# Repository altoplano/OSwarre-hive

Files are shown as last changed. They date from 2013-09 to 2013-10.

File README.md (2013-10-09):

Open Source Beehives - Warre Hive 1.0
=========

<br /><span xmlns:dct="http://purl.org/dc/terms/" property="dct:title">OS Warré Hive</span> by <a xmlns:cc="http://creativecommons.org/ns#" href="http://www.opensourcebeehives.net/" property="cc:attributionName" rel="cc:attributionURL">Open Source Beehives</a> is licensed under a <a rel="license" href="http://creativecommons.org/licenses/by-sa/3.0/deed.en_US">Creative Commons Attribution-ShareAlike 3.0 Unported License</a>.<br />Based on a work at <a xmlns:dct="http://purl.org/dc/terms/" href="http://www.opensourcebeehives.net/" rel="dct:source">http://www.opensourcebeehives.net/</a>.

# Project Overview

The Open Source Beehives project is a collaborative response to the threat faced by bee populations in industrialised nations around the world. The project proposes to design hives that can support bee colonies in a sustainable way and to monitor and track the health and behaviour of a colony as it develops. Each hive contains an open source sensory kit, The Smart Citizen Kit (SCK), which can transmit to an open data platform: [Smartcitizen.me](http://www.smartcitizen.me)

These sensor enhanced hive designs are open and freely available online, the data collected from each hive is published together with geolocations allowing for a further comparison and analysis of the hives.

## Collaboration Links

[Open Source Beehives](http://www.opensourcebeehives.net/)

[Collaboration Forum](http://community.opensourcebeehives.net/)

[Github - Main Repositories](https://github.com/opensourcebeehives)

[Twitter](https://twitter.com/OSbeehives)

[Facebook](https://www.facebook.com/opensourcebeehives)

[Donate](https://www.paypal.com/es/cgi-bin/webscr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)

##Project Partnerships

The Open Source Beehive project is a collaboration between [Fablab Barcelona](http://fablabbcn.org/), [Open Tech Forever](www.opentechforever.com), and [Valldaura](http://www.valldaura.net/).

For partnership inquiries, please email:

[hello@opensourcebeehives.net](mailto:hello@opensourcebeehives.net)

# Warre Hive 1.0 Introduction

The Open Source Warre Hive 1.0 is designed to be produced using a CNC router. It can be made from two sheets of 20mm thick wood Panel. 
Please see the Fabrication Documents for more detailed information on construction : `V1.0 Fabrication Doc.rtf`

## About the Warre Hive

> The Warré hive was invented by Abbé Émil Warré, and is also called "ruche populaire" (fr) or "The People's Hive" (en), the Warré hive is a modular and storied design similar to a Langstroth hive. The hive body is made of boxes stacked vertically; however, it uses Top Bars for comb support instead of full frames, as a general rule. The popularity of this hive is growing among sustainable-practice beekeepers.
The Warre hive differs from other stacked hive systems in one fundamental aspect: when the bees need more space as the colony expands, the new box is "nadired". i.e. positioned underneath the existing box(es). This serves the purpose of warmth retention within the brood nest of the hive, considered vital to colony health. The 1948 book "Beekeeping for All" by Abbé Warré has been translated from French in 2010 by Dr. David and Patricia Heaf and is available as a free download at; [Bee keeping for all](http://www.users.callnetuk.com/~heaf/beekeeping_for_all.pdf) More information on the Abbé and the hive is available at; [Biobees](http://warre.biobees.com/bfa.htm)

from [Wikipedia](http://en.wikipedia.org/wiki/Beehive#Warr.C3.A9_hives)

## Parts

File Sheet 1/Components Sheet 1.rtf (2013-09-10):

Sheet 1 Components :

- Roof
2 x Pitched Side Panel
2 x Side Panel
1 x Enclosure Plate

- Base Feet
4 x Bases
4 x Base cradle (small)
4 x Base cradle (big)

- Quilt Box
2 x Side Panel (with guide holes)
2 x Side Panel

- Standard Box
10 x Patterned side panel
10 x Side Handles

- View Box
2 x Window frame top bar
2 x Window frame side bar
1 x Shutter

- Base Platform
1 x Square landing pad
2 x Feet attachment bars

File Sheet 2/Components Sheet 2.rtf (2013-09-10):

Sheet 2 Components :

- Top Bars
40 x pairs of Top bars. ( 20 triangular + 20 Squared )

- Standard Box
9 x Front or Back panels

- Roof
2 x Roofing plates
1 x Top bar

- Base Platform
1 x Base Plate with ramp

- View Box
1 x Window Support (upper)
1 x Window Support (lower)
2 x Shutter Locks

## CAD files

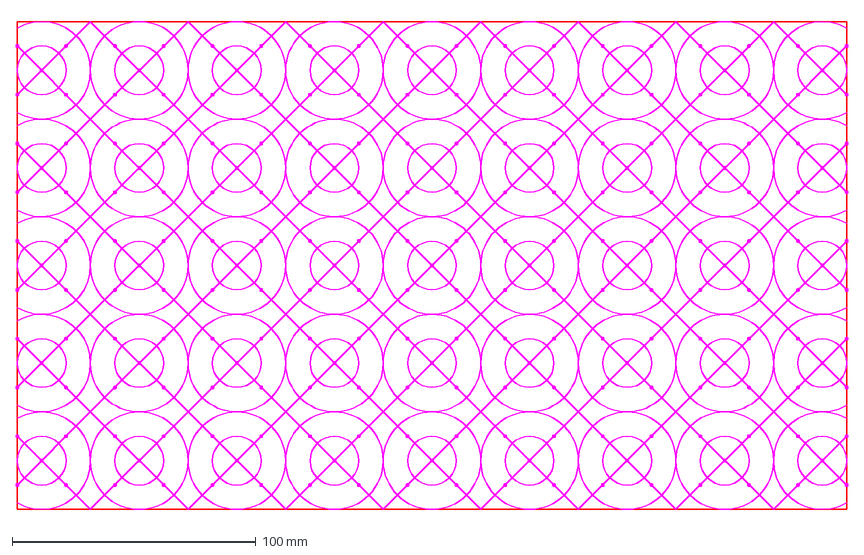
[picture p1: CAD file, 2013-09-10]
DXF Laser/Standard Box.dxf
341.0 x 204.3 mm

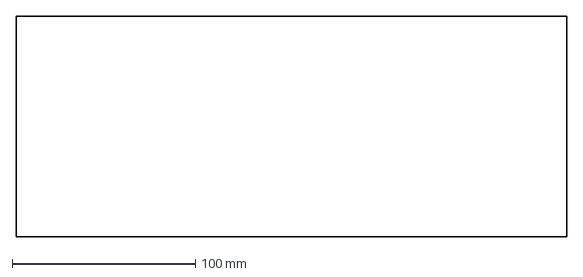
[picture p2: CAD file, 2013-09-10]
DXF Laser/Transparent.dxf
300.0 x 120.0 mm

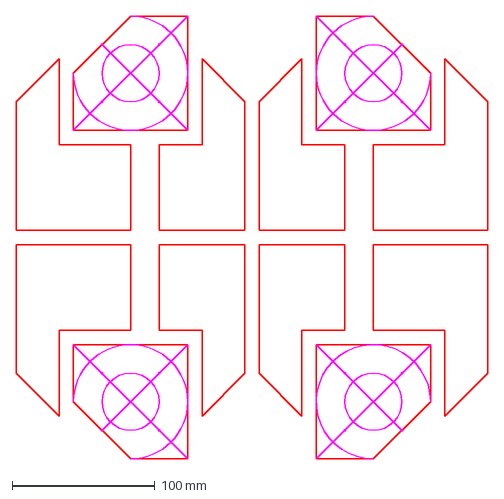
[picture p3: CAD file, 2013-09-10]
DXF Laser/feet.dxf
330.0 x 310.0 mm

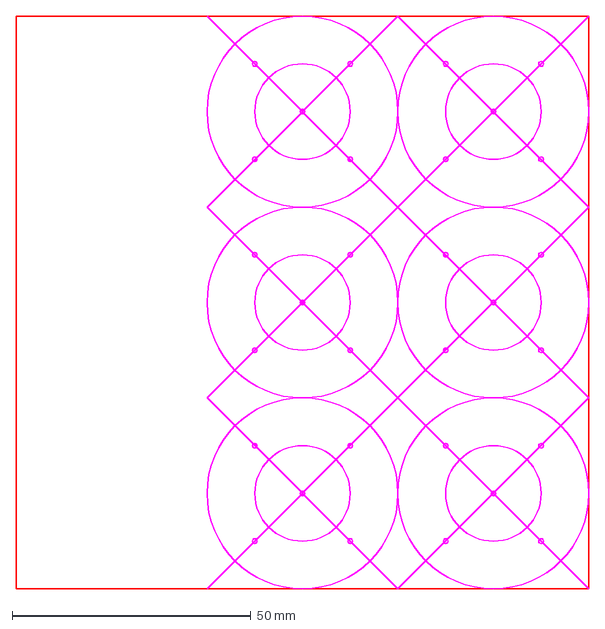
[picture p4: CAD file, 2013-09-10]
DXF Laser/landing pad.dxf
120.0 x 120.0 mm

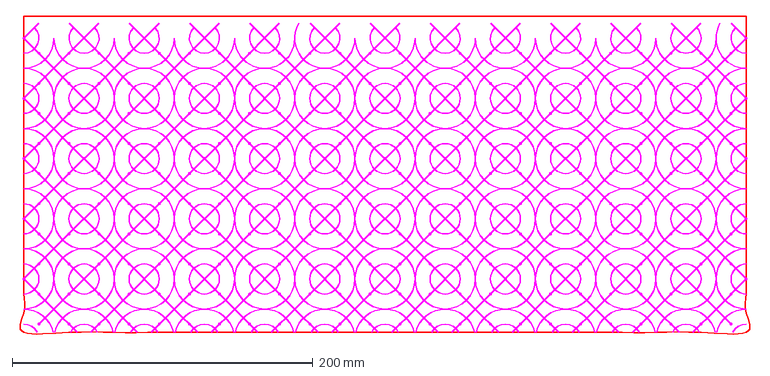
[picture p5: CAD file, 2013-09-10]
DXF Laser/Roof Box.dxf
490.0 x 212.1 mm

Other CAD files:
Sheet 1/Nesting Sheet 1.3dm

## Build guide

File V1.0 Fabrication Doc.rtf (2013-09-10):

OS Warré Hive (V 1.0)
Licensed : BYSA under the Creative Commons License system
Fabrication Documentation (V1.0)

This Open Source (OS) Warré Hive is an adaption of the Warré Hive (http://warre.biobees.com/) by Emile Warré, also known as 'The peoples hive'. It has been adjusted to fit the openstructures.net grid and also to be fabric-able and produced at a local scale and by digital manufacturing.

1. 3D CAD

All CAD designs have been made using Rhino 5. You can find a 3D model with all components in the Rhino file attached. The 3D file shows a Hive with only 3 boxes. A complete Hive can be extended to include 5 stacked boxes. All Fabrication files contain all the components for a full 5 box OS Warré Hive.

OS Warré Hive V1.3dm

2. Nesting Sheet Files

All components of the OS Warré Hive have been Nested into two Sheets also saved as Rhino files. The dimensions of these Nest documents correspond with the standard 105 x 205 x 2 cm wood panel board used in Fabrication. Each file can be used or adapted to generate multiple fabrication strategies to suit differing 3 axis milling machines.

Nesting Sheet 1.3dm
Nesting Sheet 2.3dm

3. Fabrication Strategies

The RhinoCAM plugin was used to generate the Fabrication strategies and the Gcode needed to run the Shopbot milling machine. The Nesting Sheet (.3dm) files also contain the milling path strategies. You can activate and edit these milling path strategies by running the RhinoCAM plugin. You can see the milling paths the machine will take by running this software.

The milling path files have been saved in a Gcode (.spb) format to interface with Shopbot's own CAM software. The Gcode files for each panel have been split into two sequential milling operations. These are named : "Fixings" and "Cut"

The "Fixings" files should always be run through first. They produce guide holes on the wood panels and indicate where to pin or screw them to Milling Machines sacrificial board. This will prevent your fixings getting in the way of the cutting paths. The "Cut" files should always be run second. These files contain multiple strategies and milling paths which will cut out the components.

Note that Sheet 1 contains components and strategies to cut out profiles only, whereas Sheet 2 contains components and strategies with milled pockets and gradients as well as profiles. Thus : Sheet 2 will take much longer to mill.

All strategies for have been designed to work with a 1/4 inch or 6.35 mm Flathead drill bit.

Cut Sheet 1.sbp
Fixings Sheet 1.sbp

Cut Sheet 2.sbp
Fixings Sheet 2.sbp

4. Laser Cut Patterns

Before taking the Hive components to be laser cut you should clean them and sand off the sides to be free of wood chaff. The components to engrave with the Open Structures Grid pattern are listed in the corresponding (.dxf) files below.

Each (.dxf) file only contains the vector patterns for individual components. For referencing and checking both the "Nesting Sheet.3dm" and "OS Warré Hive V1.3dm" files also contain the vectors.

On all components but the "landing pad" the side to engrave is indicated by the screw guide holes which are to be on the outset surface. You should engrave the landing pad on the reverse side as it will be screwed into the base from below.

To Engrave we used an "Epilog Laser cutter" at Speed 40 % strength : 10 %.
To Cut out the Transparent view box window from 5mm Plexiglass : Speed 15% Strength 85%

feet.dxf
landing pad.dxf
Roof Box.dxf
Standard Box.dxf
Transparent.dxf

5. Assembly

Use set squares and clamps when screwing the boxes together. 90% angles are harder to produce in a wood box than it seems. We used screws of length 35mm and with a 3mm thread. It is worth drilling pilot holes if you feel the wood may split.

In this version (V.1.0) the boxes stack up by simply resting on top of one another. They are then strapped to the ground to stop them toppling when the hive is in operation. You may with to drill in biscuit joints or dowel joint to help locate each box in a stacking series.

To finish the Hive it is recommended to use linseed oil. This should be applied liberally, left to soak in over night and then applied again. The hive may take several days to completely dry.

Improvements and Versioning Notes:

1. Replace all screw fixings by making all joints Snap fits
2. Add spaces / channels and fixings to accommodate for
2.1 The electronic boards
2.2 Sensors
2.3 Bee counter
3. Strategies to Laser the pattern before milling (could be with mill and laser reference points)
4. Add machine strategies to reduce post milling finishing by using multiple and refined tool bits.
5. Make each box stackable with a simple male / female guide. (see stacked makerbot)
6. Add removable tray at the bottom of the hive to extract detritus and dead bees.
7. Include a watering point with a moat system to allow bees to feed and repeal ants.
Credits and Contacts
22. Aug . 2013

The OS Warré Hive V.1.0 hardware has been adapted and designed by Jonathan Minchin
The OS Warré Hive V.1.0 hardware was created with the support of John Rees
The OS Warré Hive V.1.0 hardware was created with the support of Ferran Masip
The OS Warré Hive V.1.0 electronic sensors shield was designed and assembled by John Rees
The OS Warré Hive V.1.0 documentation has been produced by Jonathan Minchin
The Smart Citizen Kit was used as the basis of all electronics. Provided by Tomas Diez
The project was Instigated and coordinated by OKNO and by Annamie Maes
The project was Instigated and coordinated by Fab Lab BCN and by Tomas Diez
The Fabrication was completed at and supported by IAAC the Fab Lab Barcelona.
The OS Warré Hive V.1.0 is part of a continuing collaboration with "Open Tech Forever" called #Opensourcebeehives
